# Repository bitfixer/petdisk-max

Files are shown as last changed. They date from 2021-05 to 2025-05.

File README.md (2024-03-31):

# petdisk-max
Firmware and schematics for the PETdisk MAX storage device for Commodore PET

The PETdisk MAX is a storage device for the Commodore PET series of computers. It can use both a microSD card and can also access up to 4 network drives.
The network drives are essentially directories of files hosted on standard web servers. They can be configured as read/write or readonly. Currently PHP support is required on a web server to be used as a network drive - simply copy the [petdisk.php](https://raw.githubusercontent.com/bitfixer/petdisk-max/main/www/petdisk.php) file into a directory on a web server along with some PET files, and you're ready to go.

## Installation

The PETdisk MAX plugs into the IEEE-488 port on the back of your PET. Looking at the back of the PET, this is the edge connector on the right side.
Since the IEEE-488 port does not supply power, a separate power connection is required.
Depending on when you received your PETdisk MAX, this will either be a small board which fits into one of the PET's ROM sockets and provides a 5v power pin, or a clip which connects to the PETdisk with a wire lead.

First, open up the PET.

### For the ROM socket: 
If you have any ROM sockets free, choose the one closest to the PETdisk and install the board into the socket on the mainboard, making sure to align the notches on both sockets. 
If no ROM sockets are free, first remove a ROM chip from the mainboard, install the socket, and then reinstall the ROM chip into the new socket. Make sure to line the notches up.
Then connect the wire lead included with the PETdisk to the 5v pin, and feed the other end out the back of the PET through the opening around the IEEE-488 connector.

### For the clip: 
You'll need to clip onto a 5v source on the mainboard. An easy place to find this is on one of the 6520 chips, there are 2 of them in the PET. They are located close on the board to the IEEE-488 port. Locate one of the 6520 chips, they will be close to the back of the board and labeled '6520' somewhere on the chip. Not to be confused with the '6502' also on the board.

Locations of 6520s in some PET motherboards:\
2001: UB8 and UG8\
2001N: UC6 and UC7\
8032: UB16 and UB12

Pick the more conveniently located 6520, and find pin 20. If you are looking at the chip with the notch up, go to the left side of the chip and go down to the lower left corner. Clip on to this pin and then feed the wire lead out the back through the opening around the IEEE-488 connector.
If you prefer, you can clip on to any capacitor lead connected to 5v in the computer, there are several. 

Moving to the back of the PET, connect the wire lead to the PETdisk MAX. There is a connector on the back of the PETdisk, and the position on the connector furthest to the right side of the device is labeled '5v'. Connect here, double check that you are connected in the furthest right position, closest to the edge of the board.

After this, just plug the PETdisk MAX into the IEEE-488 connector and you're ready to go.

## Configuration

The default configuration of the PETdisk MAX uses the built-in sd card as device 8.
You can change this device number as well as setting up a maximum of 4 network drives by editing this file template:
[PETDISK.CFG](https://raw.githubusercontent.com/bitfixer/petdisk-max/main/PETDISK.CFG)\
Each line of the file consists of the drive number, comma, text specifying the drive.
SD0 refers to the built-in SD card. Change the drive number here if you like.
For network drives, the specifier is the full URL of the drive script. Up to 4 can be used at once.
Remove any lines with URLs if you don't want to use any network drives at that time.

The last 2 lines of the file contain the ssid and password for your wifi network, replace the placeholders with the information for your network. Note that only 2.4 Ghz wifi networks are supported.

Copy the edited file onto the root directory of your SD card. On the next power up, the new configuration will be read.

## Operation

Basic drive operations are the same as other Commodore storage devices.
Load a directory with
LOAD"$",devicenumber
and 
LIST

For BASIC 4, the CATALOG and DIRECTORY commands will also work.

Load a program (.PRG) with
LOAD"PROGRAM",devicenumber

or save with
SAVE"PROGRAM",devicenumber

The DLOAD command also works.

## Subdirectories

To change directories on a FAT32 volume, use
LOAD"$:dirname",devicenumber

This also loads the directory listing of the new directory.

Return to the previous directory with
LOAD"$:..",devicenumber

## D64

The PETdisk MAX currently supports D64 files for both reading and writing.
To mount a D64 file stored on either an SD card or network drive,
use the following command:
LOAD"$:filename.d64",devicenumber

This will mount the D64 file as the disk for the specified device number. It will also load the directory of the disk image which can be viewed with LIST.

To unmount the D64 file and return to the original device, use
LOAD"$:..",devicenumber

## Updating the PETdisk MAX

Firmware updates will come periodically with fixes and new features. The latest firmware for both the v1 and v2 PETdisk MAX models will be located here:\
PETdisk MAX v1 (Atmel ATmega1284)
[FIRMWARE.BIN](https://github.com/bitfixer/petdisk-max/raw/main/firmware/FIRMWARE.BIN)

PETdisk MAX v2 (ESP32):
[FIRMWARE.PD2](https://github.com/bitfixer/petdisk-max/raw/main/firmware/FIRMWARE.PD2)

To update the firmware on the device, copy this file onto the root directory of an empty microSD card formatted to FAT32. Insert the card into the PETdisk and power up. On the v1, the new firmware will be loaded onto the device after a few seconds. On the v2, the update takes about a minute during which you will first see rapid blinking on the LED, then a single blink every few seconds, followed by a few additional blinks and then the LED remains on. Once the LED is solidly on, the update is done.\
You can verify that the update worked by loading a directory from the SD card. 
At the end of the directory listing the git commit id will be listed, so you can verify it changed from before the update. This also provides a firmware ID which you can use if you need to report any bugs.

## Building the PETdisk MAX firmware

If you want to build the PETdisk MAX firmware, two versions are included in this repo. The first is a legacy version built with platformio and arduino, and is located in the 'legacy' directory. Open that directory in VSCode with the platformio plugin installed, and you should be able to build and install with the platformio menu. 
Second is a newer version built directly on esp-idf v5.1+. This is located in the 'idf' directory. With esp-idf 5.1+ installed and sourced, run 'idf.py build flash' to build and install the firmware on the device.

## Coming Soon

Things known to currently not work (but working on it):
1. Support for BASIC 1 ROM (i.e. non-upgraded original PET 2001)
2. REL files
3. U2 (block write) drive command

Please let me know if you discover any bugs or have feature requests.
bitfixer at (removeforantispam) bitfixer dot com

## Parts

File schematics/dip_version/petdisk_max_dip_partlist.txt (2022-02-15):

Partlist

Exported from petdisk_max_dip.brd at 26.01.22 23.24

EAGLE Version 9.6.1 Copyright (c) 1988-2020 Autodesk, Inc.

Assembly variant: 

Part     Value            Package                     Library             Position (mm)         Orientation

C1       10uF             1206                        SparkFun-Capacitors (72.5 17.5)           MR90
C2       10uF             1206                        SparkFun-Capacitors (62.5 17.5)           MR270
C3       0.1uF            0603-CAP                    SparkFun-Capacitors (39.3 20.7)           MR90
C5       0.1uF            0603-CAP                    SparkFun-Capacitors (26 18.3)             MR90
C6       10uF             1206                        SparkFun-Capacitors (16.2 18.5)           MR90
C7       0.1uF            0603-CAP                    SparkFun-Capacitors (18.55 17.95)         MR90
C8       10uF             1206                        SparkFun-Capacitors (23.9 18.5)           MR90
C9       10uF             1206                        SparkFun-Capacitors (60 17.5)             MR270
D1       RED              LED-0603                    SparkFun-LED        (61 26.5)             MR270
D2       RED              LED-0603                    SparkFun-LED        (57.5 26.5)           MR270
IC1      ATMEGA1284P-PU   DIP1543W58P254L5175H635Q40N rakettitiede        (38.67 16.68)         R270
IC2      NCP1117LPST33T3G SOT230P700X180-4N           rakettitiede        (67.5 17.5)           MR270
ISP      AVR_SPI_PRG_6NS  2X3-NS                      SparkFun-Connectors (5 5)                 MR180
MOD      USD-SOCKET-CHINA USD-SOCKET-PP               BaseApp             (13.5 17.5)           MR90
MOD1     ESP01            ESP01                       esp8266             (37.14 16.6)          MR90
PWRIN                     2X03                        pinhead-2           (71.04 6.44)          R270
R1       1K               0603-RES                    SparkFun-Resistors  (42.3 21.5)           MR180
R2       1K               0603-RES                    SparkFun-Resistors  (54 26.5)             MR180
R3       1K               0603-RES                    SparkFun-Resistors  (50.5 26.5)           MR180
U$1      CBM_IEEE_CONN    UPS24CONN                   commodore           (36.86 1.54)          R180
U$4      24PINEDGE        24PINEDGE                   commodore           (37.2 32.8)           R180

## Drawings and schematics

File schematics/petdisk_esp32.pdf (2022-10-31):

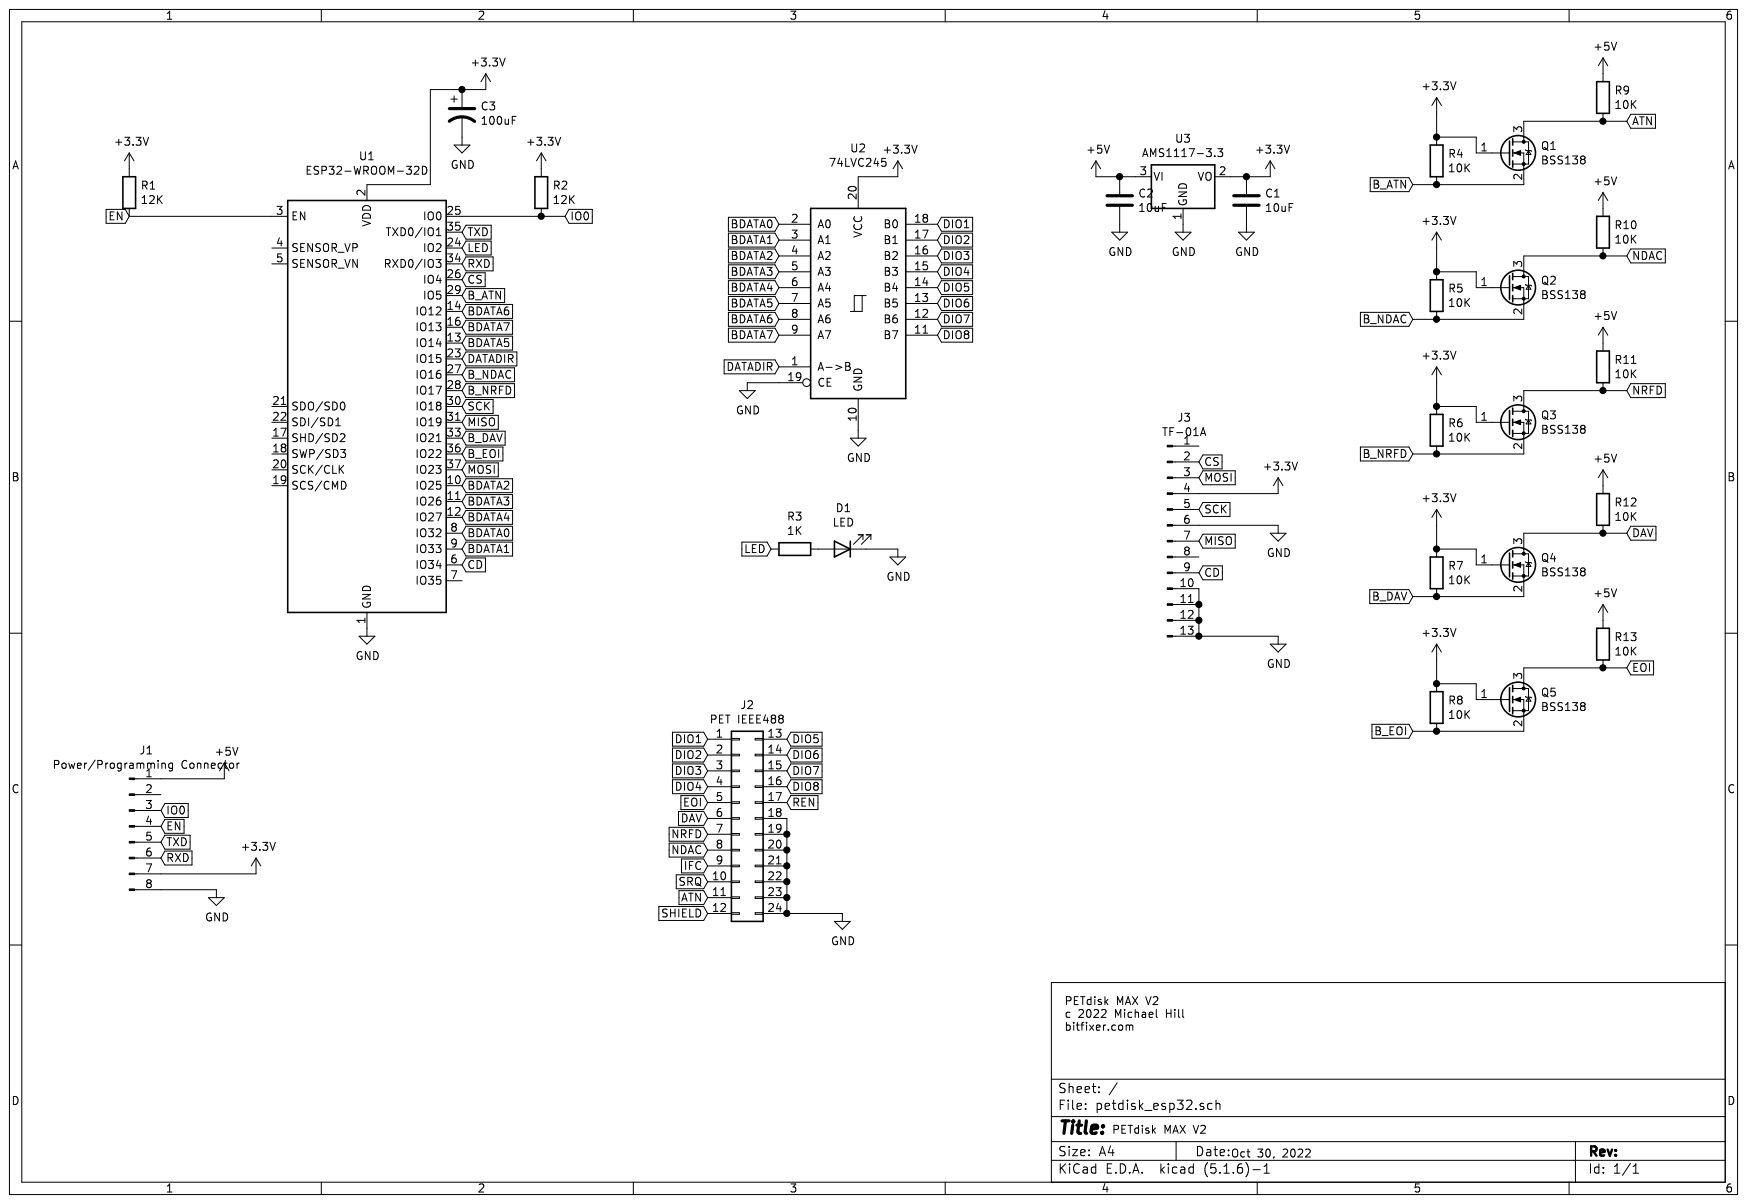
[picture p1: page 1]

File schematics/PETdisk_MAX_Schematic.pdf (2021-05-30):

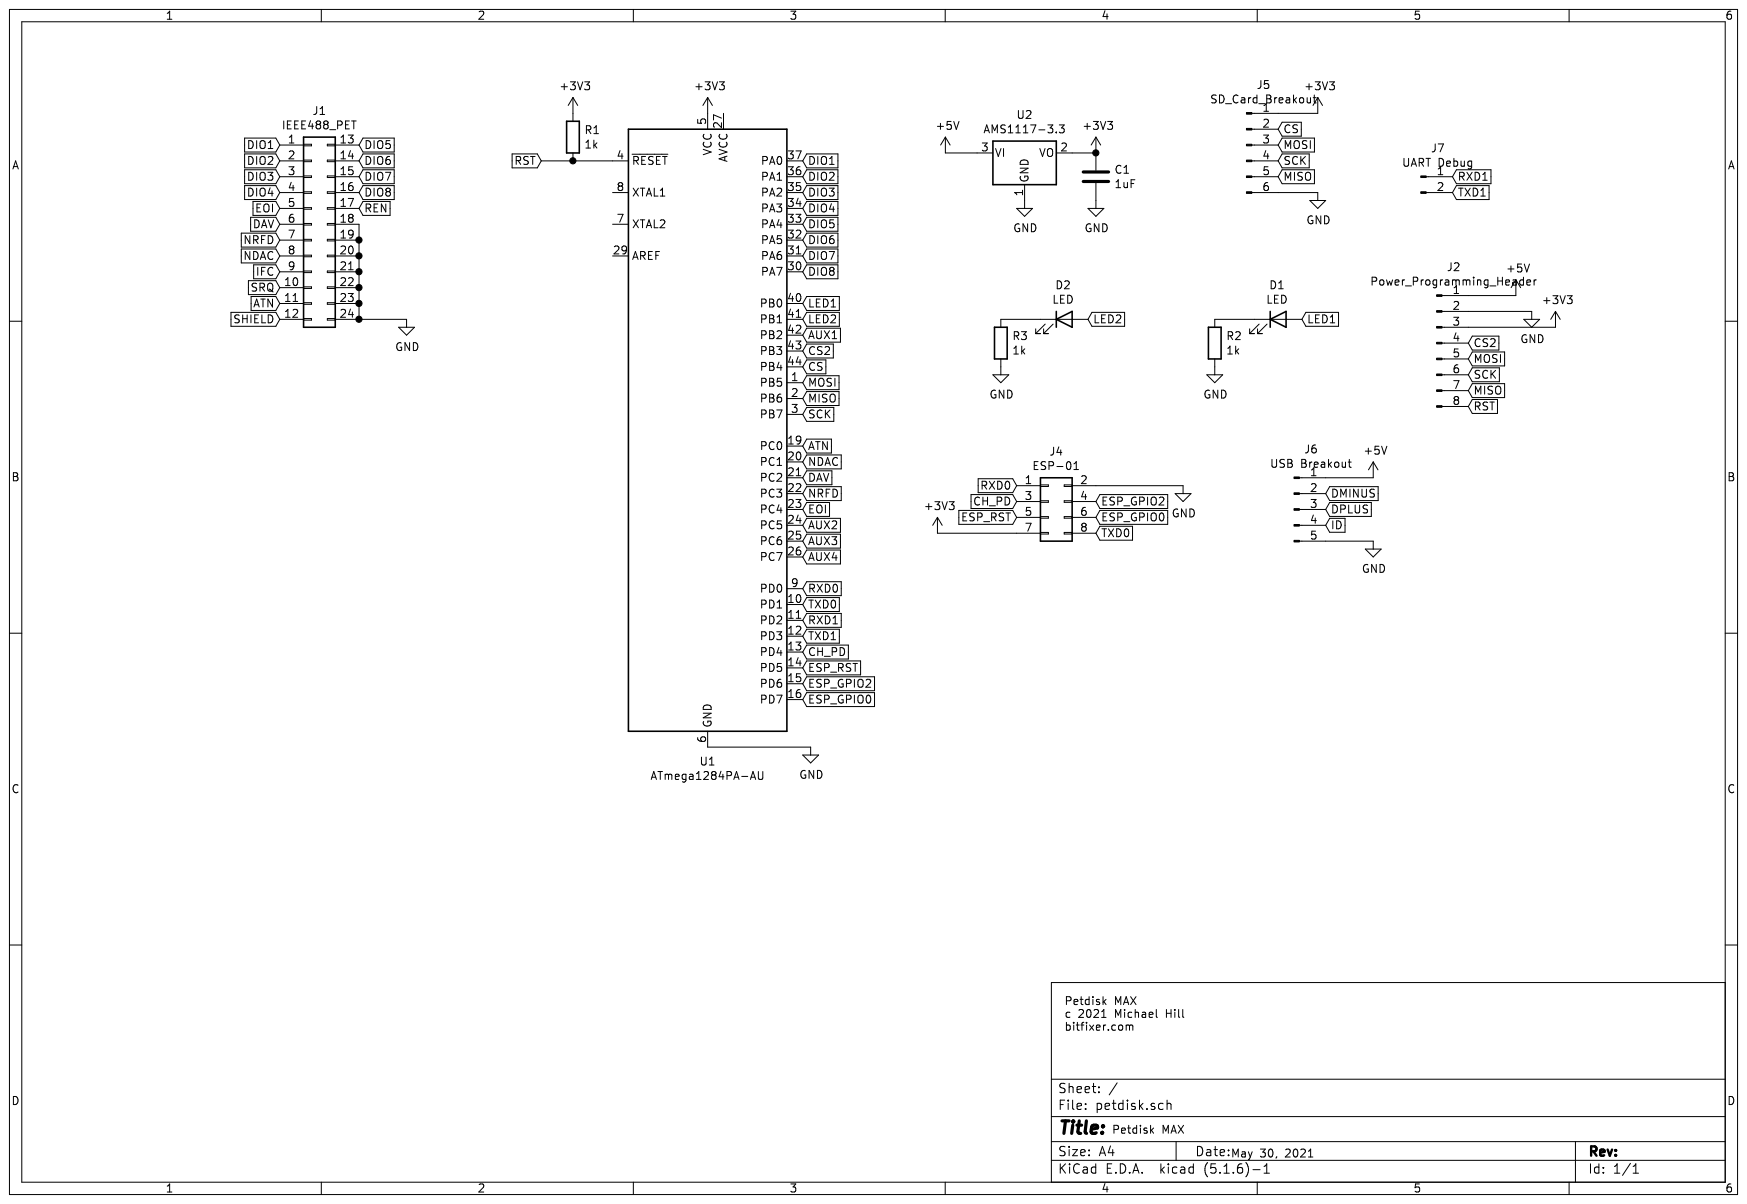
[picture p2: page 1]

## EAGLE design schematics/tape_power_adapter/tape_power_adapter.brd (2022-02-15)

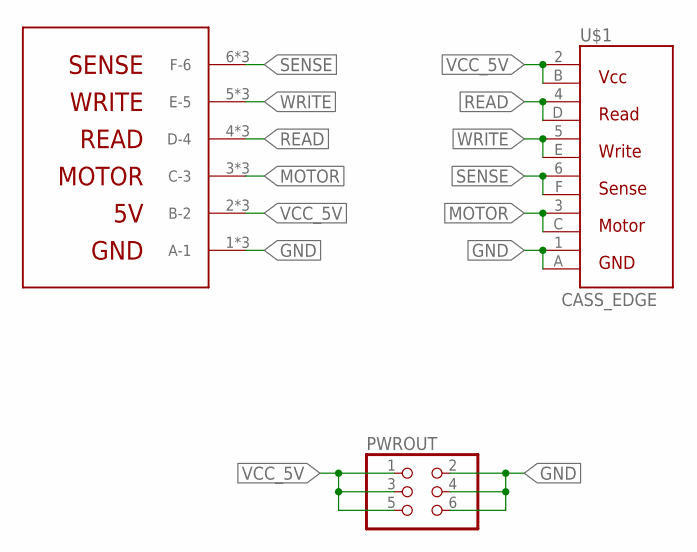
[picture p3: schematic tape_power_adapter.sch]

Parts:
PWROUT: PINHD-2X03_2.54; 2X03
U$1: CASS_EDGE; 12PINEDGE
U$2: C64CASSCONN; C64TAPECONN

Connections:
GND: PWROUT.2, PWROUT.4, PWROUT.6, U$1.1 (GND1), U$1.A (GND2), U$2.1 (A-1), U$2.1A (A-1), U$2.A (A-1)
MOTOR: U$1.3 (MOTOR1), U$1.C (MOTOR2), U$2.3 (C-3), U$2.3C (C-3), U$2.C (C-3)
READ: U$1.4 (READ1), U$1.D (READ2), U$2.4 (D-4), U$2.4D (D-4), U$2.D (D-4)
SENSE: U$1.6 (SENSE1), U$1.F (SENSE2), U$2.6 (F-6), U$2.6F (F-6), U$2.F (F-6)
VCC_5V: PWROUT.1, PWROUT.3, PWROUT.5, U$1.2 (VCC1), U$1.B (VCC2), U$2.2 (B-2), U$2.2B (B-2), U$2.B (B-2)
WRITE: U$1.5 (WRITE1), U$1.E (WRITE2), U$2.5 (E-5), U$2.5E (E-5), U$2.E (E-5)

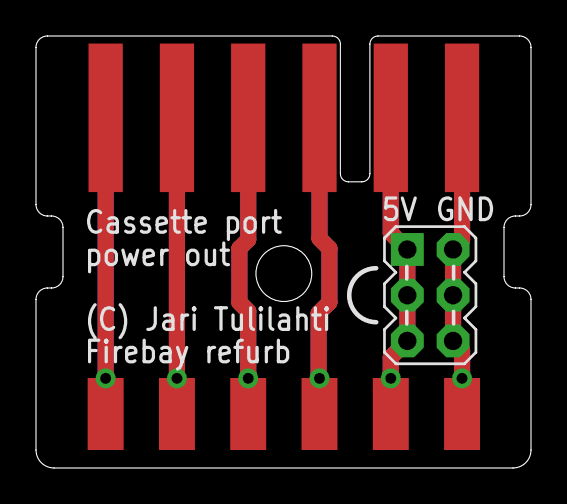
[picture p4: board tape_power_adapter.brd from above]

Board: 2 copper layers, 27.5 x 24.0 mm, 3 parts (0 on the bottom side), 6 nets.

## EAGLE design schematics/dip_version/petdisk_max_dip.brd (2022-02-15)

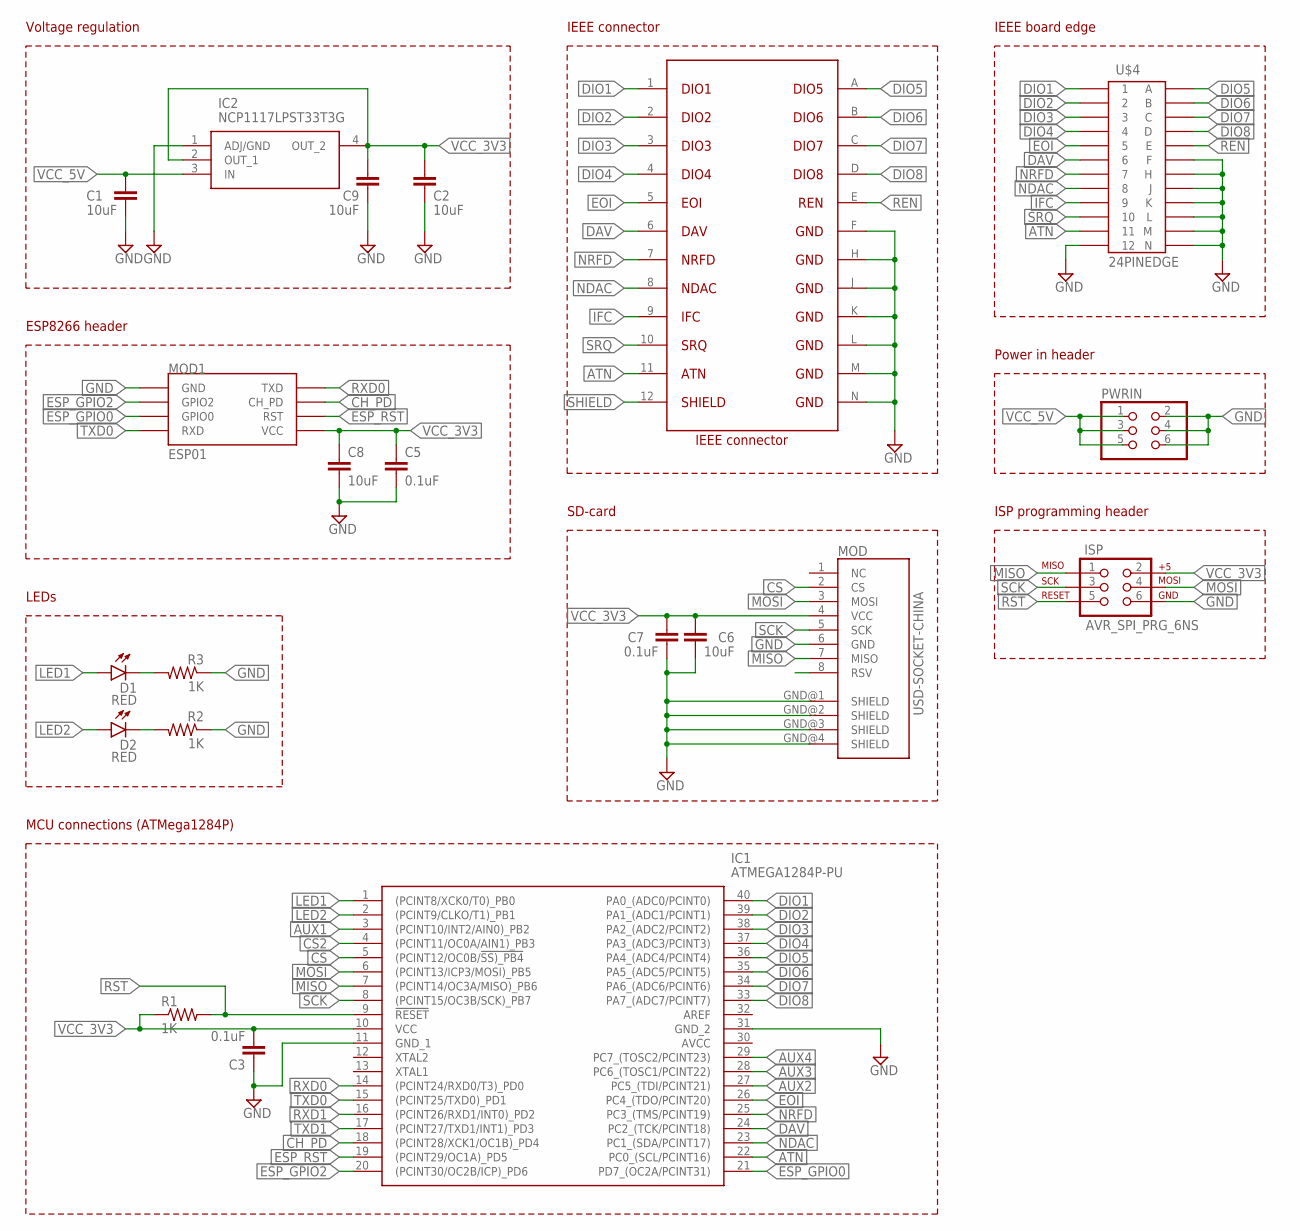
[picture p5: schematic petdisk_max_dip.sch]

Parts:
C1, C2, C6, C8, C9: 10uF; 1206
C3, C5, C7: 0.1uF; 0603-CAP
D1, D2: RED; LED-0603
IC1: ATMEGA1284P-PU; DIP1543W58P254L5175H635Q40N
IC2: NCP1117LPST33T3G; SOT230P700X180-4N
ISP: AVR_SPI_PRG_6NS; 2X3-NS
MOD: USD-SOCKET-CHINA; USD-SOCKET-PP
MOD1: ESP01
PWRIN: PINHD-2X03_2.54; 2X03
R1, R2, R3: 1K; 0603-RES
U$1: CBM_IEEE_CONN; UPS24CONN
U$4: 24PINEDGE

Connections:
ATN: IC1.22 (PC0_(SCL/PCINT16)), U$1.11, U$4.11
AUX1: IC1.3 ((PCINT10/INT2/AIN0)_PB2)
AUX2: IC1.27 (PC5_(TDI/PCINT21))
AUX3: IC1.28 (PC6_(TOSC1/PCINT22))
AUX4: IC1.29 (PC7_(TOSC2/PCINT23))
CH_PD: IC1.18 ((PCINT28/XCK1/OC1B)_PD4), MOD1.CH_PD
CS: IC1.5 ((PCINT12/OC0B/!SS)_PB4), MOD.2 (CS)
CS2: IC1.4 ((PCINT11/OC0A/AIN1)_PB3)
DAV: IC1.24 (PC2_(TCK/PCINT18)), U$1.6, U$4.6
DIO1: IC1.40 (PA0_(ADC0/PCINT0)), U$1.1, U$4.1
DIO2: IC1.39 (PA1_(ADC1/PCINT1)), U$1.2, U$4.2
DIO3: IC1.38 (PA2_(ADC2/PCINT2)), U$1.3, U$4.3
DIO4: IC1.37 (PA3_(ADC3/PCINT3)), U$1.4, U$4.4
DIO5: IC1.36 (PA4_(ADC4/PCINT4)), U$1.A, U$4.A
DIO6: IC1.35 (PA5_(ADC5/PCINT5)), U$1.B, U$4.B
DIO7: IC1.34 (PA6_(ADC6/PCINT6)), U$1.C, U$4.C
DIO8: IC1.33 (PA7_(ADC7/PCINT7)), U$1.D, U$4.D
EOI: IC1.26 (PC4_(TDO/PCINT20)), U$1.5, U$4.5
ESP_GPIO0: IC1.21 (PD7_(OC2A/PCINT31)), MOD1.GPIO0
ESP_GPIO2: IC1.20 ((PCINT30/OC2B/ICP)_PD6), MOD1.GPIO2
ESP_RST: IC1.19 ((PCINT29/OC1A)_PD5), MOD1.RST
GND: C1.2, C2.2, C3.1, C5.2, C6.2, C7.2, C8.2, C9.2, IC1.11 (GND_1), IC1.31 (GND_2), IC2.1 (ADJ/GND), ISP.6, MOD.6 (GND), MOD.GND@1 (SHIELD), MOD.GND@2 (SHIELD), MOD.GND@3 (SHIELD), MOD.GND@4 (SHIELD), MOD1.GND, PWRIN.2, PWRIN.4, PWRIN.6, R2.1, R3.1, U$1.F, U$1.H, U$1.J, U$1.K, U$1.L, U$1.M, U$1.N, U$4.12, U$4.F, U$4.H, U$4.J, U$4.K, U$4.L, U$4.M, U$4.N
IFC: U$1.9, U$4.9
LED1: D1.A, IC1.1 ((PCINT8/XCK0/T0)_PB0)
LED2: D2.A, IC1.2 ((PCINT9/CLKO/T1)_PB1)
MISO: IC1.7 ((PCINT14/OC3A/MISO)_PB6), ISP.1, MOD.7 (MISO)
MOSI: IC1.6 ((PCINT13/ICP3/MOSI)_PB5), ISP.4, MOD.3 (MOSI)
unnamed: D1.C, R3.2
unnamed: D2.C, R2.2
NDAC: IC1.23 (PC1_(SDA/PCINT17)), U$1.8, U$4.8
NRFD: IC1.25 (PC3_(TMS/PCINT19)), U$1.7, U$4.7
REN: U$1.E, U$4.E
RST: IC1.9 (!RESET), ISP.5, R1.2
RXD0: IC1.14 ((PCINT24/RXD0/T3)_PD0), MOD1.TX (TXD)
RXD1: IC1.16 ((PCINT26/RXD1/INT0)_PD2)
SCK: IC1.8 ((PCINT15/OC3B/SCK)_PB7), ISP.3, MOD.5 (SCK)
SHIELD: U$1.12
SRQ: U$1.10, U$4.10
TXD0: IC1.15 ((PCINT25/TXD0)_PD1), MOD1.RX (RXD)
TXD1: IC1.17 ((PCINT27/TXD1/INT1)_PD3)
VCC_3V3: C2.1, C3.2, C5.1, C6.1, C7.1, C8.1, C9.1, IC1.10 (VCC), IC2.2 (OUT_1), IC2.4 (OUT_2), ISP.2, MOD.4 (VCC), MOD1.VCC, R1.1
VCC_5V: C1.1, IC2.3 (IN), PWRIN.1, PWRIN.3, PWRIN.5

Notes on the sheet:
Voltage regulation
IEEE connector
ESP8266 header
MCU connections (ATMega1284P)
SD-card
LEDs
IEEE board edge
Power in header
ISP programming header

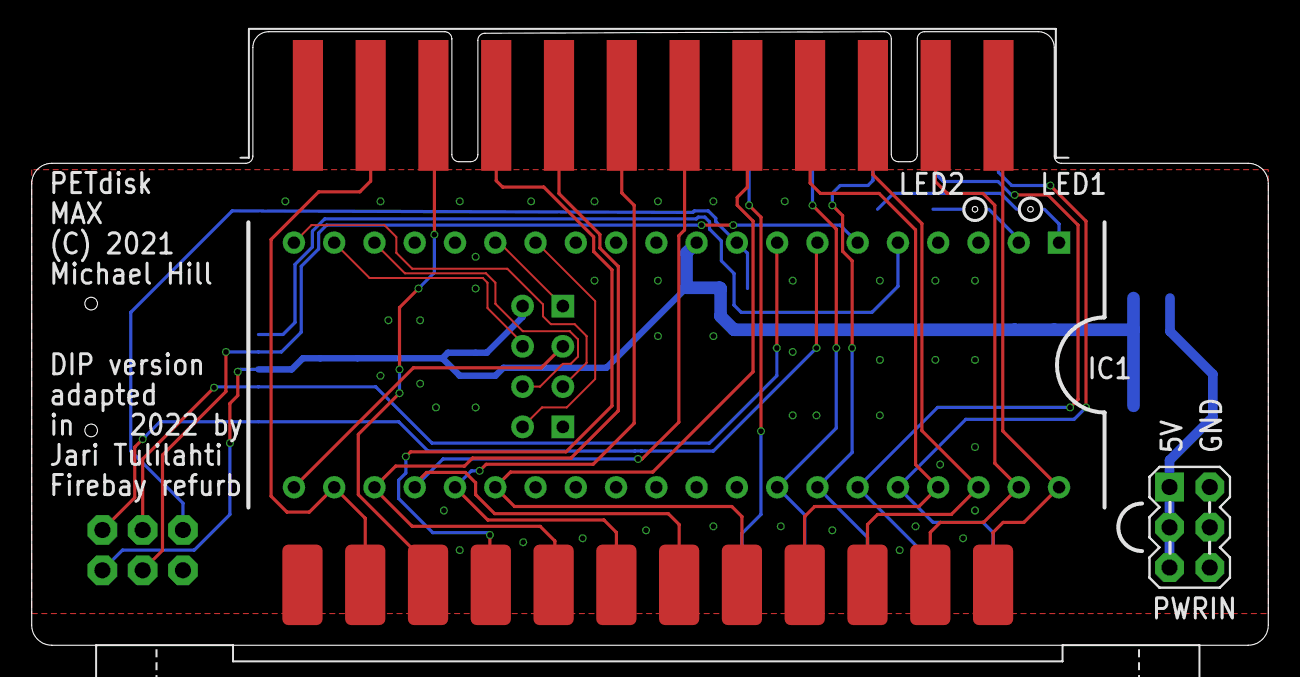
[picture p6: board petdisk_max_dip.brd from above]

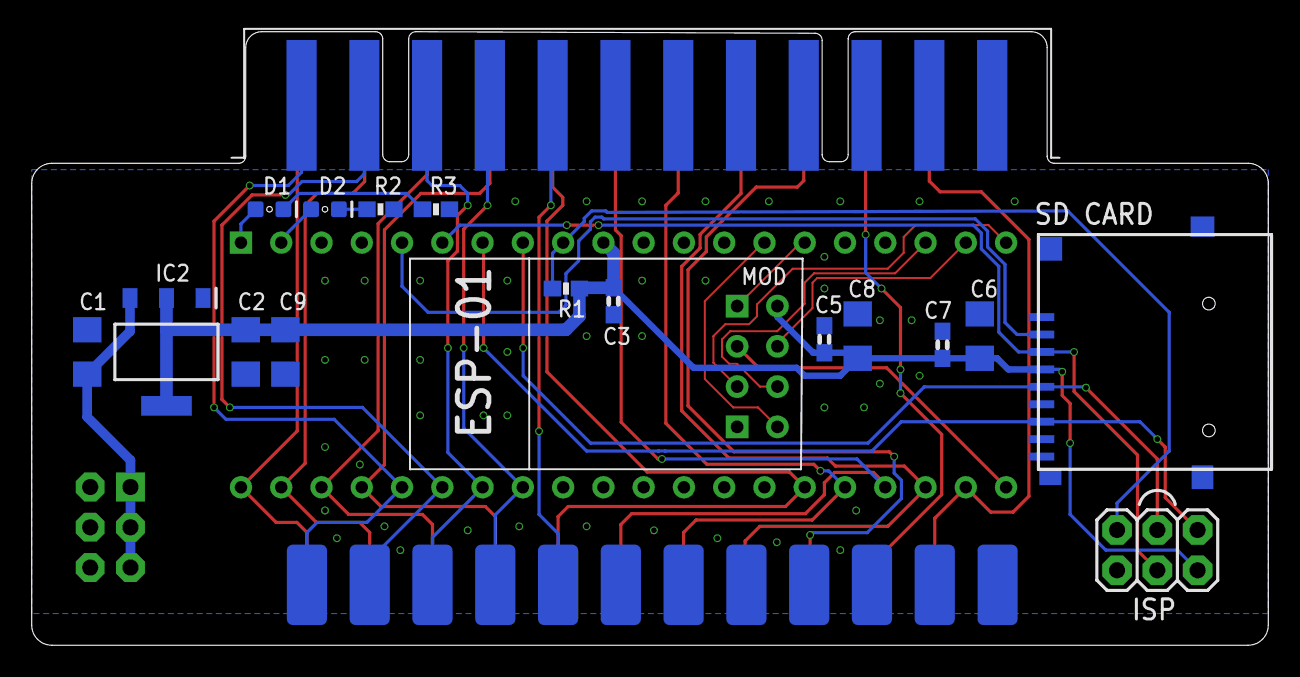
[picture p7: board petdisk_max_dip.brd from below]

Board: 2 copper layers, 78.0 x 38.7 mm, 21 parts (17 on the bottom side), 34 nets.

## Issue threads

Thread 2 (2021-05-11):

Saving inside a .D64 seems to have corrupted it

natevw, 2021-05-11:
I had a .D64 disk image "open" via `LOAD"$:DISK.D64",8` when I saved a BASIC program via `SAVE"TEST",8` and this seems to have corrupted the disk image. See attached file — it used to have more than a dozen games and now only a handful of them are seen when doing a directory listing.

(Nothing valuable lost since this was just a downloaded file I copied onto the card in the first place but thought it might be worth reporting…)

[TEHGAMES-brokt.D64.zip](https://github.com/bitfixer/petdisk-max/files/6456744/TEHGAMES-brokt.D64.zip)

natevw, 2021-05-17:
Here's the original file I was using. (In case it matters: when it happened the file was called `TEHGAME.D64` before I realized it had a bunch of separate games in it :-)

[TEHGAMES.D64.zip](https://github.com/bitfixer/petdisk-max/files/6497231/TEHGAMES.D64.zip)

natevw, 2021-05-17:
(whoops, didn't mean to close this issue yet just bumped the wrong button…)

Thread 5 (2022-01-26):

DIP version of PETDisk Max

Jartza, 2022-01-26:
Hi,

As you may know, the availability of ATMega1284p in SMD is pretty much non-existing before next year. I noticed though, that Digikey has around 4000 of those in DIP size packages.

So I solved the problem of not getting PETDisk Max myself by designing a DIP version. Some components are SMD and they are all placed underside the board (so you can still order SMD-populated board from JLC for example). I also solved the problem of getting power to the board by designing passthrough to cassette port, where you can take power. Also the PETDisk Max itself has passthrough in the PCB.

I tested this (without ESP-module as I don't have a use for it) and it seems to work :)

If there's any interest, I could drop PCB files & Gerbers here? (I'm still using Eagle, unfortunately haven't had time to really master Kicad yet).

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

Jartza, 2022-01-26:
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

bitfixer, 2022-01-26:
Hi, this is great! Congratulations on the new layout. Would be happy to
have this on the repo, if you like you could mail those to me and I will
put them up, or send me a PR for it.
Good solution with the power from the cassette port, this was what I had
for the original PETdisk (before it was MAX) and works well. Do you have
the data lines from the cassette port brought over to the other board? I
had this and they were connected to a couple of spare pins on the MCU,
always intended to implement a cassette loader this way but never did it.
The chip shortage does seem to have struck with the atmega chips, seems
like there have been none available for a couple of months at least. A
preview of the next version of the PETdisk MAX - I decided to switch over
from using an ATMega1284 to using an ESP32 module in the next board
revision, which seems to be widely available right now. This means only one
microcontroller on the board and no separate wifi module, saves a bit of
board cost as well as being a more capable microcontroller in general. Got
the firmware ported over to the new platform, but kept everything almost
completely the same so future firmware updates will be built for both
platforms.
Again congratulations on the board design and happy to put it up on the
repo. Thanks,
- Mike
***@***.***

On Wed, Jan 26, 2022 at 6:11 AM Jari Tulilahti ***@***.***>
wrote:

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

Jartza, 2022-01-26:
Hi. I can make a pull request :)

I only brought in the 5V and GND lines, actually both 3 times (as those 6-pin crimpable connectors for flat cable are easy to crimp) . But of course as there's Eagle files available, it's easy to modify them.

Jartza, 2022-01-26:
I think actually Kicad opens Eagle files without issues as well.

I now also verified that the ESP-01 is working with this DIP-version. The only differences are that this is missing the UART pins and reset-button but those should be easy to add.

Jartza, 2022-01-26:
https://github.com/bitfixer/petdisk-max/pull/6

Jartza, 2022-01-26:
Tape adapter:

https://github.com/bitfixer/petdisk-max/pull/8

Jartza, 2022-02-07:
Two pull requests as I did fumble something and couldn't get them into single one 😄

Jartza, 2022-02-25:
Looks like the PRs have been merged, thanks. I'm closing this issue.

Closed 2022-02-25.

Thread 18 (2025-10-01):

Can't Build Firmware 2.1

ntydelski, 2025-10-01:
I can't build the firmware I get his error every time?" Linking CXX executable petdisk-max.elf
FAILED: petdisk-max.elf"   Why is that? I'm trying to program my board.  Thankyou

[110/111] Generating binary image from built executable
esptool.py v4.10.0
Creating esp32 image...
Merged 2 ELF sections
Successfully created esp32 image.
Generated C:/Espressif/petdisk-max-2.1/build/bootloader/bootloader.bin
[111/111] C:\Windows\system32\cmd.exe /C "cd /D C:\Espress...Espressif/petdisk-max-2.1/build/bootloader/bootloader.bin"
Bootloader binary size 0x6570 bytes. 0xa90 bytes (9%) free.
[993/995] Linking CXX executable petdisk-max.elf
FAILED: petdisk-max.elf
C:\Windows\system32\cmd.exe /C "cd . && C:\Espressif\tools\xtensa-esp-elf\esp-14.2.0_20241119\xtensa-esp-elf\bin\xtensa-esp32-elf-g++.exe -mlongcalls -Wno-frame-address  -fno-builtin-memcpy -fno-builtin-memset -fno-builtin-bzero -fno-builtin-stpcpy -fno-builtin-strncpy -Wl,--cref -Wl,--defsym=IDF_TARGET_ESP32=0 -Wl,--Map=C:/Espressif/petdisk-max-2.1/build/petdisk-max.map -Wl,--no-warn-rwx-segments -Wl,--orphan-handling=warn -fno-rtti -fno-lto -Wl,--gc-sections -Wl,--warn-common -T esp32.peripherals.ld -T esp32.rom.ld -T esp32.rom.api.ld -T esp32.rom.libgcc.ld -T esp32.rom.newlib-data.ld -T esp32.rom.syscalls.ld -T esp32.rom.newlib-funcs.ld -T memory.ld -T sections.ld @CMakeFiles\petdisk-max.elf.rsp -o petdisk-max.elf && cd ."
C:/Espressif/tools/xtensa-esp-elf/esp-14.2.0_20241119/xtensa-esp-elf/bin/../lib/gcc/xtensa-esp-elf/14.2.0/../../../../xtensa-esp-elf/bin/ld.exe: esp-idf/freertos/libfreertos.a(app_startup.c.obj):(.literal.main_task+0x24): undefined reference to `app_main'
C:/Espressif/tools/xtensa-esp-elf/esp-14.2.0_20241119/xtensa-esp-elf/bin/../lib/gcc/xtensa-esp-elf/14.2.0/../../../../xtensa-esp-elf/bin/ld.exe: esp-idf/freertos/libfreertos.a(app_startup.c.obj): in function `main_task':
C:/Espressif/frameworks/esp-idf-v5.4.2/components/freertos/app_startup.c:206:(.text.main_task+0x95): undefined reference to `app_main'
collect2.exe: error: ld returned 1 exit status
ninja: build stopped: subcommand failed.
ninja failed with exit code 1, output of the command is in the C:\Espressif\petdisk-max-2.1\build\log\idf_py_stderr_output_3900 and C:\Espressif\petdisk-max-2.1\build\log\idf_py_stdout_output_3900
PS C:\Espressif\petdisk-max-2.1>

Closed 2025-10-01.

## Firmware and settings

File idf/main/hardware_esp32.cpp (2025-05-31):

#include "hardware.h"
#include <string.h>
#include <freertos/FreeRTOS.h>
#include <freertos/task.h>
#include <freertos/queue.h>
#include <driver/uart.h>
#include <driver/gpio.h>
#include <driver/spi_common.h>
#include <driver/spi_master.h>
#include <freertos/semphr.h>

#include <hal/gpio_hal.h>

#include <esp_log.h>
#include <nvs_flash.h>
#include <esp_timer.h>
#include <nvs.h>
#include <esp_cpu.h>

#include "console.h"
#include "IEEE488.h"

static const char* TAG = "hw";

#ifdef CONFIG_IDF_TARGET_ESP32
uint32_t data_mask_low[256];
uint32_t data_mask_hi[256];
#endif

void gpio_init() {
    // set all used io pins as output
    //zero-initialize the config structure.
    gpio_config_t io_conf;
    memset(&io_conf, 0, sizeof(gpio_config_t));
    //disable interrupt
    io_conf.intr_type = GPIO_INTR_DISABLE;
    //set as input mode
    io_conf.mode = (gpio_mode_t)INPUT_PULLUP;
    //bit mask of the pins that you want to set,e.g.GPIO18/19

    io_conf.pin_bit_mask = 1ULL << DATA0;
    io_conf.pin_bit_mask |= 1ULL << DATA1;
    io_conf.pin_bit_mask |= 1ULL << DATA2;
    io_conf.pin_bit_mask |= 1ULL << DATA3;
    io_conf.pin_bit_mask |= 1ULL << DATA4;
    io_conf.pin_bit_mask |= 1ULL << DATA5;
    io_conf.pin_bit_mask |= 1ULL << DATA6;
    io_conf.pin_bit_mask |= 1ULL << DATA7;

    io_conf.pin_bit_mask |= 1ULL << DATADIR;

    io_conf.pin_bit_mask |= 1ULL << ATN_PIN;
    io_conf.pin_bit_mask |= 1ULL << EOI_PIN;
    io_conf.pin_bit_mask |= 1ULL << DAV_PIN;
    io_conf.pin_bit_mask |= 1ULL << NRFD_PIN;
    io_conf.pin_bit_mask |= 1ULL << NDAC_PIN;

    io_conf.pin_bit_mask |= 1ULL << LED_PIN;

    //disable pull-down mode
    io_conf.pull_down_en = (gpio_pulldown_t)0;
    //disable pull-up mode
    io_conf.pull_up_en = (gpio_pullup_t)1;
    //configure GPIO with the given settings
    gpio_config(&io_conf);

    #ifdef CONFIG_IDF_TARGET_ESP32
    int data_pins[8];
    data_pins[0] = DATA0;
    data_pins[1] = DATA1;
    data_pins[2] = DATA2;
    data_pins[3] = DATA3;
    data_pins[4] = DATA4;
    data_pins[5] = DATA5;
    data_pins[6] = DATA6;
    data_pins[7] = DATA7;

    int pin_order[8];
    pin_order[0] = 0;
    pin_order[1] = 1;
    pin_order[2] = 6;
    pin_order[3] = 7;
    pin_order[4] = 5;
    pin_order[5] = 2;
    pin_order[6] = 3;
    pin_order[7] = 4;

    // prepare data masks, high and low registers
    for (int i = 0; i < 256; i++) {
        uint32_t low_mask = 0;
        uint32_t high_mask = 0;

        uint8_t byte = (uint8_t)i;
        for (int i = 0; i < 8; i++) {
            int data_pin = data_pins[i];
            if (byte & 0x1) {
                if (data_pin >= 32) {
                    high_mask |= (1 << (data_pin-32));
                } else {
                    low_mask |= (1 << data_pin);
                }
            }
            byte >>= 1;
        }

        ESP_LOGV(TAG, "datamask %X: %lX %lX", i, low_mask, high_mask);

        data_mask_low[i] = low_mask;
        data_mask_hi[i] = high_mask;
    }
    #endif

    EspFastGpio::init();
}

void setPinMode(int pin, int mode) {
    //zero-initialize the config structure.
    gpio_config_t io_conf;
    memset(&io_conf, 0, sizeof(gpio_config_t));
    //disable interrupt
    io_conf.intr_type = GPIO_INTR_DISABLE;
    //set as output mode
    io_conf.mode = (gpio_mode_t)mode;
    //bit mask of the pins that you want to set,e.g.GPIO18/19
    io_conf.pin_bit_mask = 1ULL << pin;
    //disable pull-down mode
    io_conf.pull_down_en = (gpio_pulldown_t)0;
    //disable pull-up mode
    io_conf.pull_up_en = (gpio_pullup_t)1;
    //configure GPIO with the given settings
    gpio_config(&io_conf);
}

uint8_t spi_cs()
{
    return CS_PIN;
}

static nvs_handle_t eeprom_nvs_handle;
static uint8_t eeprom_data[512];

void prog_init()
{
    // nothing for esp32
    set_atn_input();

    // initialize nvs
    esp_err_t err = nvs_flash_init();
    if (err == ESP_ERR_NVS_NO_FREE_PAGES || err == ESP_ERR_NVS_NEW_VERSION_FOUND) {
        // NVS partition was truncated and needs to be erased
        // Retry nvs_flash_init
        ESP_ERROR_CHECK(nvs_flash_erase());
        err = nvs_flash_init();
    }
    if (err != ESP_OK) {
        ESP_LOGE(TAG, "nvs init failed");
    }

    err = nvs_open("storage", NVS_READWRITE, &eeprom_nvs_handle);
    if (err != ESP_OK) {
        ESP_LOGE(TAG, "nvs_open failed");
    }

    // read eeprom data into ram
    size_t size = 512;
    err = nvs_get_blob(eeprom_nvs_handle, "eeprom", eeprom_data, &size);
    if (err != ESP_OK) {
        ESP_LOGE(TAG, "eeprom_write_block: failed to read");
        memset(eeprom_data, 0, 512);
    }
}

void init_led()
{
    fast_gpio_set_output(LED_PIN);
}

void set_led(bool value)
{
    if (value == true)
    {
        fast_gpio_set_high(LED_PIN);
    }
    else
    {
        fast_gpio_set_low(LED_PIN);
    }
}

// ====
// test function
static int ledinit(int argc, char** argv) {
    printf("running init_led\n");
    init_led();
    return 0;
}
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

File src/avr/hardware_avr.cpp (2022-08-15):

#include "../hardware.h"

#include <stdio.h>
#include <string.h>
#include <util/delay.h>
#include <avr/io.h>
#include <avr/interrupt.h>
#include <avr/pgmspace.h>
#include <avr/eeprom.h>

#define ESP_CONTROL     DDRD
#define ESP_PORT        PORTD
#define ESP_CH_PD       PD4
#define ESP_RST         PD5
#define ESP_GPIO0       PD7
#define ESP_GPIO2       PD6

#define LED_CONTROL     DDRB
#define LED_PORT        PORTB
#define LED_PIN1        PB0
#define LED_PIN2        PB1

#define SPI_CONTROL     DDRB
#define SPI_PORT        PORTB
#define SPI_CS          PB4
#define SPI_CS2         PB3
#define SPI_MOSI        PB5
#define SPI_SCK         PB7

#define SPI_CS_MASK     1<<SPI_CS
#define NOT_SPI_CS_MASK ~(SPI_CS_MASK)

uint8_t spi_cs()
{
    return SPI_CS;
}

void prog_init()
{
     // set reset for esp
    ESP_PORT = (1 << ESP_CH_PD) | (1 << ESP_RST);
    ESP_CONTROL = (1 << ESP_CH_PD) | (1 << ESP_RST);
    sei();
}

void reset_esp()
{
    ESP_PORT &= ~(1 << ESP_RST);
    ESP_PORT &= ~(1 << ESP_CH_PD);

    for (int i = 0; i < 20; i++)
    {
        _delay_loop_2(65535);
    }

    ESP_PORT |= 1 << ESP_RST;
    ESP_PORT |= 1 << ESP_CH_PD;
    hDelayMs(500);
}

void init_led()
{
    LED_CONTROL |= 1 << LED_PIN1;
    LED_CONTROL |= 1 << LED_PIN2;
}

void set_led(bool value)
{
    if (value == true)
    {
        LED_PORT |= 1 << LED_PIN1;
        LED_PORT |= 1 << LED_PIN2;
    }
    else
    {
        LED_PORT &= ~(1 << LED_PIN1);
        LED_PORT &= ~(1 << LED_PIN2);
    }
}

void hDelayMs(int ms)
{
    for (int i = 0; i < ms; i++)
    {
        _delay_ms(1);
    }
}

uint8_t bf_pgm_read_byte(uint8_t* src)
{
  return pgm_read_byte(src);
}

void bf_eeprom_write_block(const void* block, void* eeprom, size_t n)
{
    eeprom_write_block(block, eeprom, n);
}

void bf_eeprom_read_block(void* block, const void* eeprom, size_t n)
{
    eeprom_read_block(block, eeprom, n);
}

uint8_t bf_eeprom_read_byte(const uint8_t* addr)
{
    return eeprom_read_byte(addr);
}

// SPI

void spi_init()
{
    SPI_PORT = 0x00;
    SPI_PORT |= 1 << SPI_CS;
    SPI_PORT |= 1 << SPI_CS2;
    SPI_CONTROL |= 1 << SPI_CS;
    SPI_CONTROL |= 1 << SPI_CS2;
    SPI_CONTROL |= 1 << SPI_MOSI;
    SPI_CONTROL |= 1 << SPI_SCK; 

    SPCR = 0x52;
    SPSR = 0x00;
}

uint8_t spi_transmit(uint8_t data)
{
    SPDR = data;
    while ( !(SPSR & (1<<SPIF)) ) {}

    data = SPDR;
    return data;
}

void spi_cs_select()
{
    SPI_PORT &= NOT_SPI_CS_MASK;
}

void spi_cs_unselect()
{
    SPI_PORT |= SPI_CS_MASK;
}

// serial

uint32_t bRnd(float f)
{
    uint32_t i = (uint32_t)f;
    float r = f - (float)i;

    if (r >= 0.5f)
    {
        return i+1;
    }
    else
    {
        return i;
    }
}

uint8_t ubrrFromBaudRate(uint32_t baudRate, bool* doubleSpeed)
{
    // try regular speed first
    float fRegUbrr = (float(F_CPU) / float(16*baudRate)) - 1.0f;
    uint32_t regUbrr = bRnd(fRegUbrr);
    // get real baud rate
    uint32_t actualRegBr = (float(F_CPU) / float(16*(regUbrr+1)));
    float regErr = 1.0 - (float)actualRegBr / (float)baudRate;
    if (regErr < 0.0) {
        regErr = -regErr;
    }

    // try double speed
    float fDblUbrr = (float(F_CPU) / float(8*baudRate)) - 1.0f;
    uint32_t dblUbrr = bRnd(fDblUbrr);
    // get real baud rate
    uint32_t actualDblBr = (F_CPU / (8*(dblUbrr+1)));
    float dblErr = 1.0 - (float)actualDblBr / (float)baudRate;
    if (dblErr < 0.0) {
        dblErr = -dblErr;
    }

    if (regErr <= dblErr) {
        *doubleSpeed = false;
        return (uint8_t)regUbrr;
    } else {
        *doubleSpeed = true;
        return (uint8_t)dblUbrr;
    }
}

void serial0_init(uint32_t baudRate)
{
    bool double_speed;
    uint8_t ubrr = ubrrFromBaudRate(baudRate, &double_speed);

    UBRR0H = (unsigned char)(ubrr>>8);
    UBRR0L = (unsigned char)ubrr;
    UCSR0A = double_speed ? (1<<U2X0) : 0x00;
    UCSR0B = (1<<RXEN0)|(1<<TXEN0);
    UCSR0C = (1<<USBS0)|(3<<UCSZ00);
}

void serial0_transmitByte(unsigned char data)
{
    while ( !(UCSR0A & (1<<UDRE0)) ) {}
    UDR0 = data;
}

unsigned char serial0_receiveByte()
{
    unsigned char data;
    while ( !(UCSR0A & (1<<RXC0)) ) {}
    data = UDR0;
    return(data);
}

void serial0_enable_interrupt()
{
    UCSR0B |= (1 << RXCIE0);
}

void serial0_disable_interrupt()
{
    UCSR0B &= ~(1 << RXCIE0);
}

void serial1_init(uint32_t baudRate)
{
    bool double_speed;
    uint8_t ubrr = ubrrFromBaudRate(baudRate, &double_speed);

    UBRR1H = (unsigned char)(ubrr>>8);
    UBRR1L = (unsigned char)ubrr;
    UCSR1A = double_speed ? (1<<U2X1) : 0x00;
    UCSR1B = (1<<RXEN1)|(1<<TXEN1);
    UCSR1C = (1<<USBS1)|(3<<UCSZ10);
}

void serial1_transmitByte(unsigned char data)
{
    while ( !(UCSR1A & (1<<UDRE1)) ) {}
    UDR1 = data;
}

unsigned char serial1_receiveByte()
{
    unsigned char data;
    while ( !(UCSR1A & (1<<RXC1)) ) {}
    data = UDR1;
    return(data);
}

void serial1_enable_interrupt()
{
    UCSR1B |= (1 << RXCIE1);
}
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

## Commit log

2021-02-12 cleanup and fixed behavior when no card is in the slot
2021-02-14 WIP adding multiple open file info structs, to track multiple open files
2021-02-22 added ability to mount d64 drive from another datasource
2021-02-22 mount and unmount d64 file
2021-03-20 added PETDISK.CFG
    [PETDISK.CFG]
2021-03-23 turn on led after loading
2021-04-07 last line of dir prints
2021-05-30 added schematics
2021-05-30 updated schematic
2021-09-10 fix for directory bug, init was clobbering current directory cluster
2022-01-11 first working version after esp32 refactor
2022-01-12 WIP integrating esp32 build, moving code
2022-01-21 use pgmspace for esp32, cleanup
2022-01-27 added sd loader as separate target
    [partitions.csv]
2022-02-03 added some led blinks to bootloader
2022-02-15 PCB for ATMega1284p DIP-version, made with Eagle. Includes Gerbers. (#6)
    * PCB for ATMega1284p DIP-version, made with Eagle. Includes Gerbers.
    * Add partlist
    [petdisk_max_dip.brd, petdisk_max_dip.sch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]
2022-02-15 Tape power adapter PCB, made with Eagle. Includes gerbers (#8)
    [tape_power_adapter.brd, tape_power_adapter.sch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]
2022-02-17 add delay after resetting esp
    [hardware_avr.cpp]
2022-03-25 change firmware file name for esp32 version
2022-10-31 added petdisk max v2 schematic
2023-08-09 different frameworks for sd_loader and petdisk
2023-08-10 Revert "different frameworks for sd_loader and petdisk"
    This reverts commit 275c9e9d205cee63d39655ab769179abf2e22230.
2024-03-31 move legacy code
    [PETDISK.CFG, partitions.csv]
2025-01-10 make sure to use default configuration if no devices are set
2025-04-25 Adding support for esp32-s2 with petdisk (#15)
    * added console
    * console commands
    * more test functions
    * led test functions
    * fix gpio for s2
    * WIP new http datasource
    * wip
    * new http stuff
    * http datasource testing
    * testing for http ds and psram
    * fix s2 pins
    * usb cdc console, testing without psram
    * cleanup
    * reading works, faster io
    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
    [partitions.csv]
2025-04-25 esp32 changes
2025-04-25 1000 hz rtos
2025-04-26 Revert "simplify atn wait"
    This reverts commit 71fb65469f8b745354c8b24662cafc46ba5d572d.
    [hardware_esp32.cpp]
2025-04-30 malloc for esp32 crash fix
    [console.cpp]
2025-05-09 disable interrupts for esp32, loading better
2025-05-13 Revert "disable interrupts for esp32, loading better"
    This reverts commit 715cf07410be6d4e3c7f957cb8d5a760885bc049.
2025-05-13 no disabling interrupts
2025-05-13 network loading on esp32 working better
2025-05-14 set led, fix interrupt crash
    [hardware_esp32.cpp]
2025-05-21 added esp-fast-gpio library, rework io (#16)
    * added esp-fast-gpio
    * moving gpio to lib
    * more cleanup
    * input/output mask
    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
    [hardware_esp32.cpp, hardware_esp32.h]
2025-05-28 clean up esp32 data macros
2025-05-28 add timeout to atn high, prevents getting stuck if pet is off
    [hardware_esp32.cpp, hardware_esp32.h]
2025-05-31 clean up spi
2025-05-31 use spi interface
2025-10-01 fix esp32 build
2025-11-24 automate build assembly
2026-05-29 moved petdisk config, removed unused cmake file
    [PETDISK.CFG]
2026-05-29 Refactor sdfat (#21)
    * attempt at rebuilding FAT32 datasource with IDF fatfs
    * wip sdfat partially working
    * use long filenames for fatfs
    * added card detect interrupt
    * added card detect pin for esp32
    ---------

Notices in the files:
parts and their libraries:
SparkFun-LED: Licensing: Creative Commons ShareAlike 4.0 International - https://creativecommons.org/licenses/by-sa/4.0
